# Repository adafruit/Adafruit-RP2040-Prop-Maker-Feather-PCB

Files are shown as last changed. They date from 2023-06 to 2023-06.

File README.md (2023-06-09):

## Adafruit RP2040 Prop-Maker Feather with I2S Audio Amplifier PCB

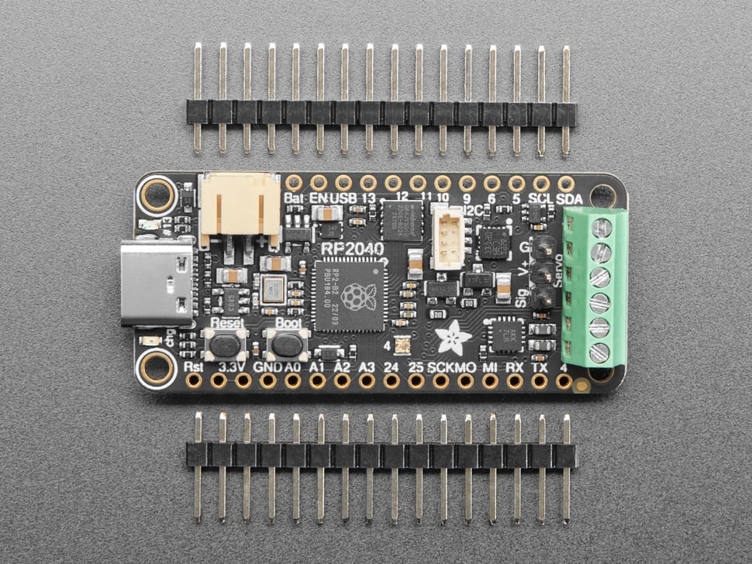
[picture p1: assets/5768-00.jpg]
<a href="http://www.adafruit.com/products/5768"><br/>
Click here to purchase one from the Adafruit shop</a>

PCB files for the Adafruit RP2040 Prop-Maker Feather with I2S Audio Amplifier. 

Format is EagleCAD schematic and board layout
* https://www.adafruit.com/product/5768

### Description

The Adafruit Feather series gives you lots of options for a small, portable, rechargeable microcontroller board. By picking a feather and stacking on a FeatherWing you can create advanced projects quickly. One popular combo is our Feather M4 or Feather RP2040 with a Prop-Maker FeatherWing on top to create animatronics or props that boot up instantly and can drive LEDs, and small speakers.

We've used the Prop-Maker FeatherWing to make lots of lil robots, swords, and other prop projects. However, what if we made it even easier for people to make props? What if we made it so many projects can be built with minimal or no soldering at all? Yeah that would be pretty nice!

Thus, the creation of the Feather P2040 Prop-Maker: an all-in-one combination of the Feather RP2040 with a Prop-Maker FeatherWing with a few tweaks based on feedback from expert prop-builders. Perfect for fitting into your next prop build! This Feather will unlock the prop-maker inside all of us, with tons of stuff packed in to make sabers & swords, props, toys, cosplay pieces, and more.

We looked at hundreds of prop builds, and thought about what would make for a great low-cost (but well-designed) add-on for our Feather boards. Here's what we came up with:

* Terminal Block NeoPixel Port - With easy-to-use screw terminals you can quickly connect and disconnect your NeoPixel strips and rings. This port provides high current drive from either the Feather Lipoly or USB port, whichever is higher. A 5V level up-shifter gives you a clean voltage signal to reduce glitchiness no matter what chip you're using. You can also cut power to the entire strip instantly to reduce quiescent power, thanks to a separate control transistor.
* MAX98357 I2S 3 Watt Class D Audio Amplifier - Drive any 4-8Ω speaker, up to 3 Watts, for sound effects. Audio comes out on two of the terminal blocks so you can screw in any wires to a speaker you like - we're partial to this small 3W speaker with pre-attached wires. Thanks to the I2S digital inputs, you'll get excellent audio quality
* Triple-Axis Accelerometer with Tap Detection - The LIS3DH is our favorite accelerometer, you can use this for detection motion, tilt, or taps. Here's an example of a lightsaber that makes sounds when swung or hit. We have code for this chip in both Arduino and CircuitPython.
* Extra Button or Output Pin - One more pin on the terminal screw block can be used for button input or digital output, for activation or a simple LED.
* Servo Connection - Plug any hobby servo with 3 wires into the 0.1" spaced header, and you can have quick motion control.
* Low power mode! The power system for the NeoPixels and speaker amplifier can be controlled by a pin to cut power to them, so you have lower power usage when the prop is in sleep or off mode (but can wake up fast by listening to the button press or accelerometer data).

At the Feather's heart is an RP2040 chip, clocked at 133 MHz and at 3.3V logic, the same one used in the Raspberry Pi Pico. This chip has a whopping 8 MB of onboard QSPI FLASH and 264K of RAM!  There's even room left over for a STEMMA QT connector for plug-and-play of I2C devices.

To make it easy to use for portable projects, we added a connector for any of our 3.7V Lithium polymer batteries and built in battery charging. You don't need a battery, it will run just fine straight from the USB Type C connector. But, if you do have a battery, you can take it on the go, then plug in the USB to recharge. The Feather will automatically switch over to USB power when it's available.

Here're some handy specs! You get:

* Measures 52.1mm x 22.8mm x 12.2mm / 2.1" x 0.9" x 0.5 without headers soldered in
* Light as a (large?) feather - ~7grams
* RP2040 32-bit Cortex M0+ dual core running at ~133 MHz @ 3.3V logic and power
* 264 KB RAM
* 8 MB SPI FLASH chip for storing files, images, and CircuitPython/MicroPython code storage. No EEPROM
* Tons of GPIO! 21 x GPIO pins with following capabilities:
	* Four 12-bit ADCs (one more than Pico)
	* Two I2C, Two SPI, and two UART peripherals, we label one for the 'main' interface in standard Feather locations
	* 16 x PWM outputs - for servos, LEDs, etc
* Built-in 200mA+ lipoly charger with charging status indicator LED
* Pin #13 red LED for general purpose blinking
* RGB NeoPixel for full-color indication.
* On-board STEMMA QT connector that lets you quickly connect any Qwiic, STEMMA QT or Grove I2C devices with no soldering!
* Both Reset button and Bootloader select button for quick restarts (no unplugging-replugging to relaunch code)
* USB Type C connector lets you access built-in ROM USB bootloader and serial port debugging
* 3.3V regulator with 500mA peak current output and power enable pin
* 4 mounting holes
* 12 MHz crystal for perfect timing.
* Prop-Making section with I2S 3W audio amplifier, 5V NeoPixel level shifting, accelerometer, servo port, and terminal blocks for fast solder-free connections.

Comes assembled and tested, with some header. You'll need a soldering iron to attach the header if you'd like to use it on a breadboard!

### License

Adafruit invests time and resources providing this open source design, please support Adafruit and open-source hardware by purchasing products from [Adafruit](https://www.adafruit.com)!

Designed by Limor Fried/Ladyada for Adafruit Industries.

Creative Commons Attribution/Share-Alike, all text above must be included in any redistribution. 
See license.txt for additional details.

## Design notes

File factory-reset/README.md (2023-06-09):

## Factory Reset file - RP2040 Prop-Maker Feather with I2S Audio Amplifier

This is the factory reset file for the RP2040 Prop-Maker Feather with I2S Audio Amplifier.

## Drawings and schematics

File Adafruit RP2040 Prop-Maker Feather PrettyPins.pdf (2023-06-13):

# Adafruit RP2040 Prop-Maker Feather

# https://www.adafruit.com/product/5768

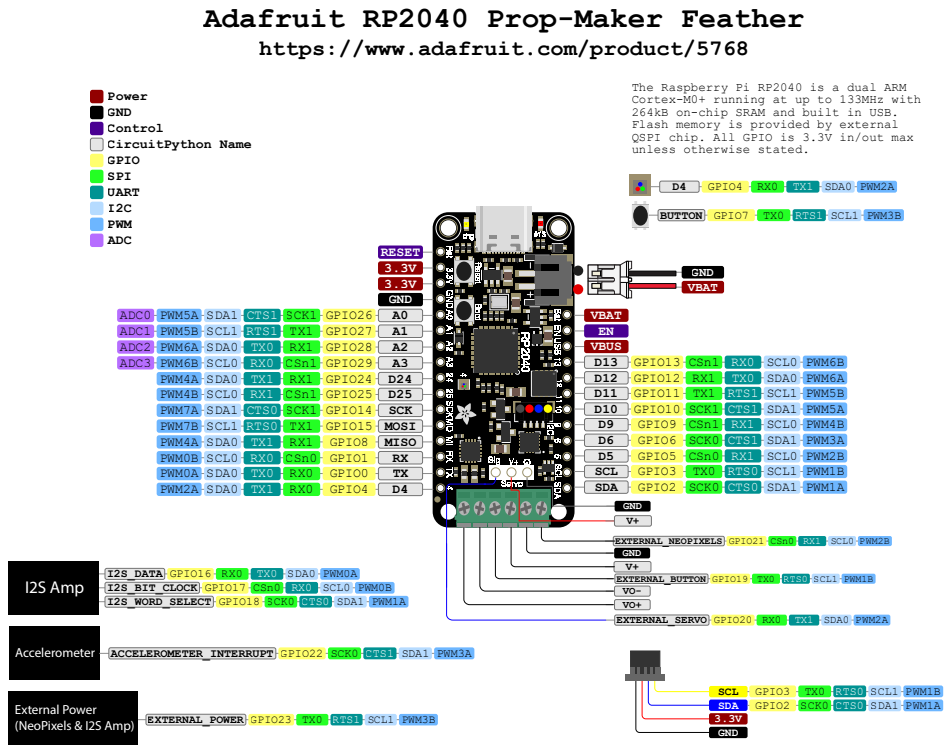
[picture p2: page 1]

The Raspberry Pi RP2040 is a dual ARM
Cortex-M0+ running at up to 133MHz with
264kB on-chip SRAM and built in USB.
Flash memory is provided by external
QSPI chip. All GPIO is 3.3V in/out max
unless otherwise stated.
D4 GPIO4 RX0 TX1 SDA0 PWM2A
BUTTON GPIO7 TX0 RTS1 SCL1 PWM3B

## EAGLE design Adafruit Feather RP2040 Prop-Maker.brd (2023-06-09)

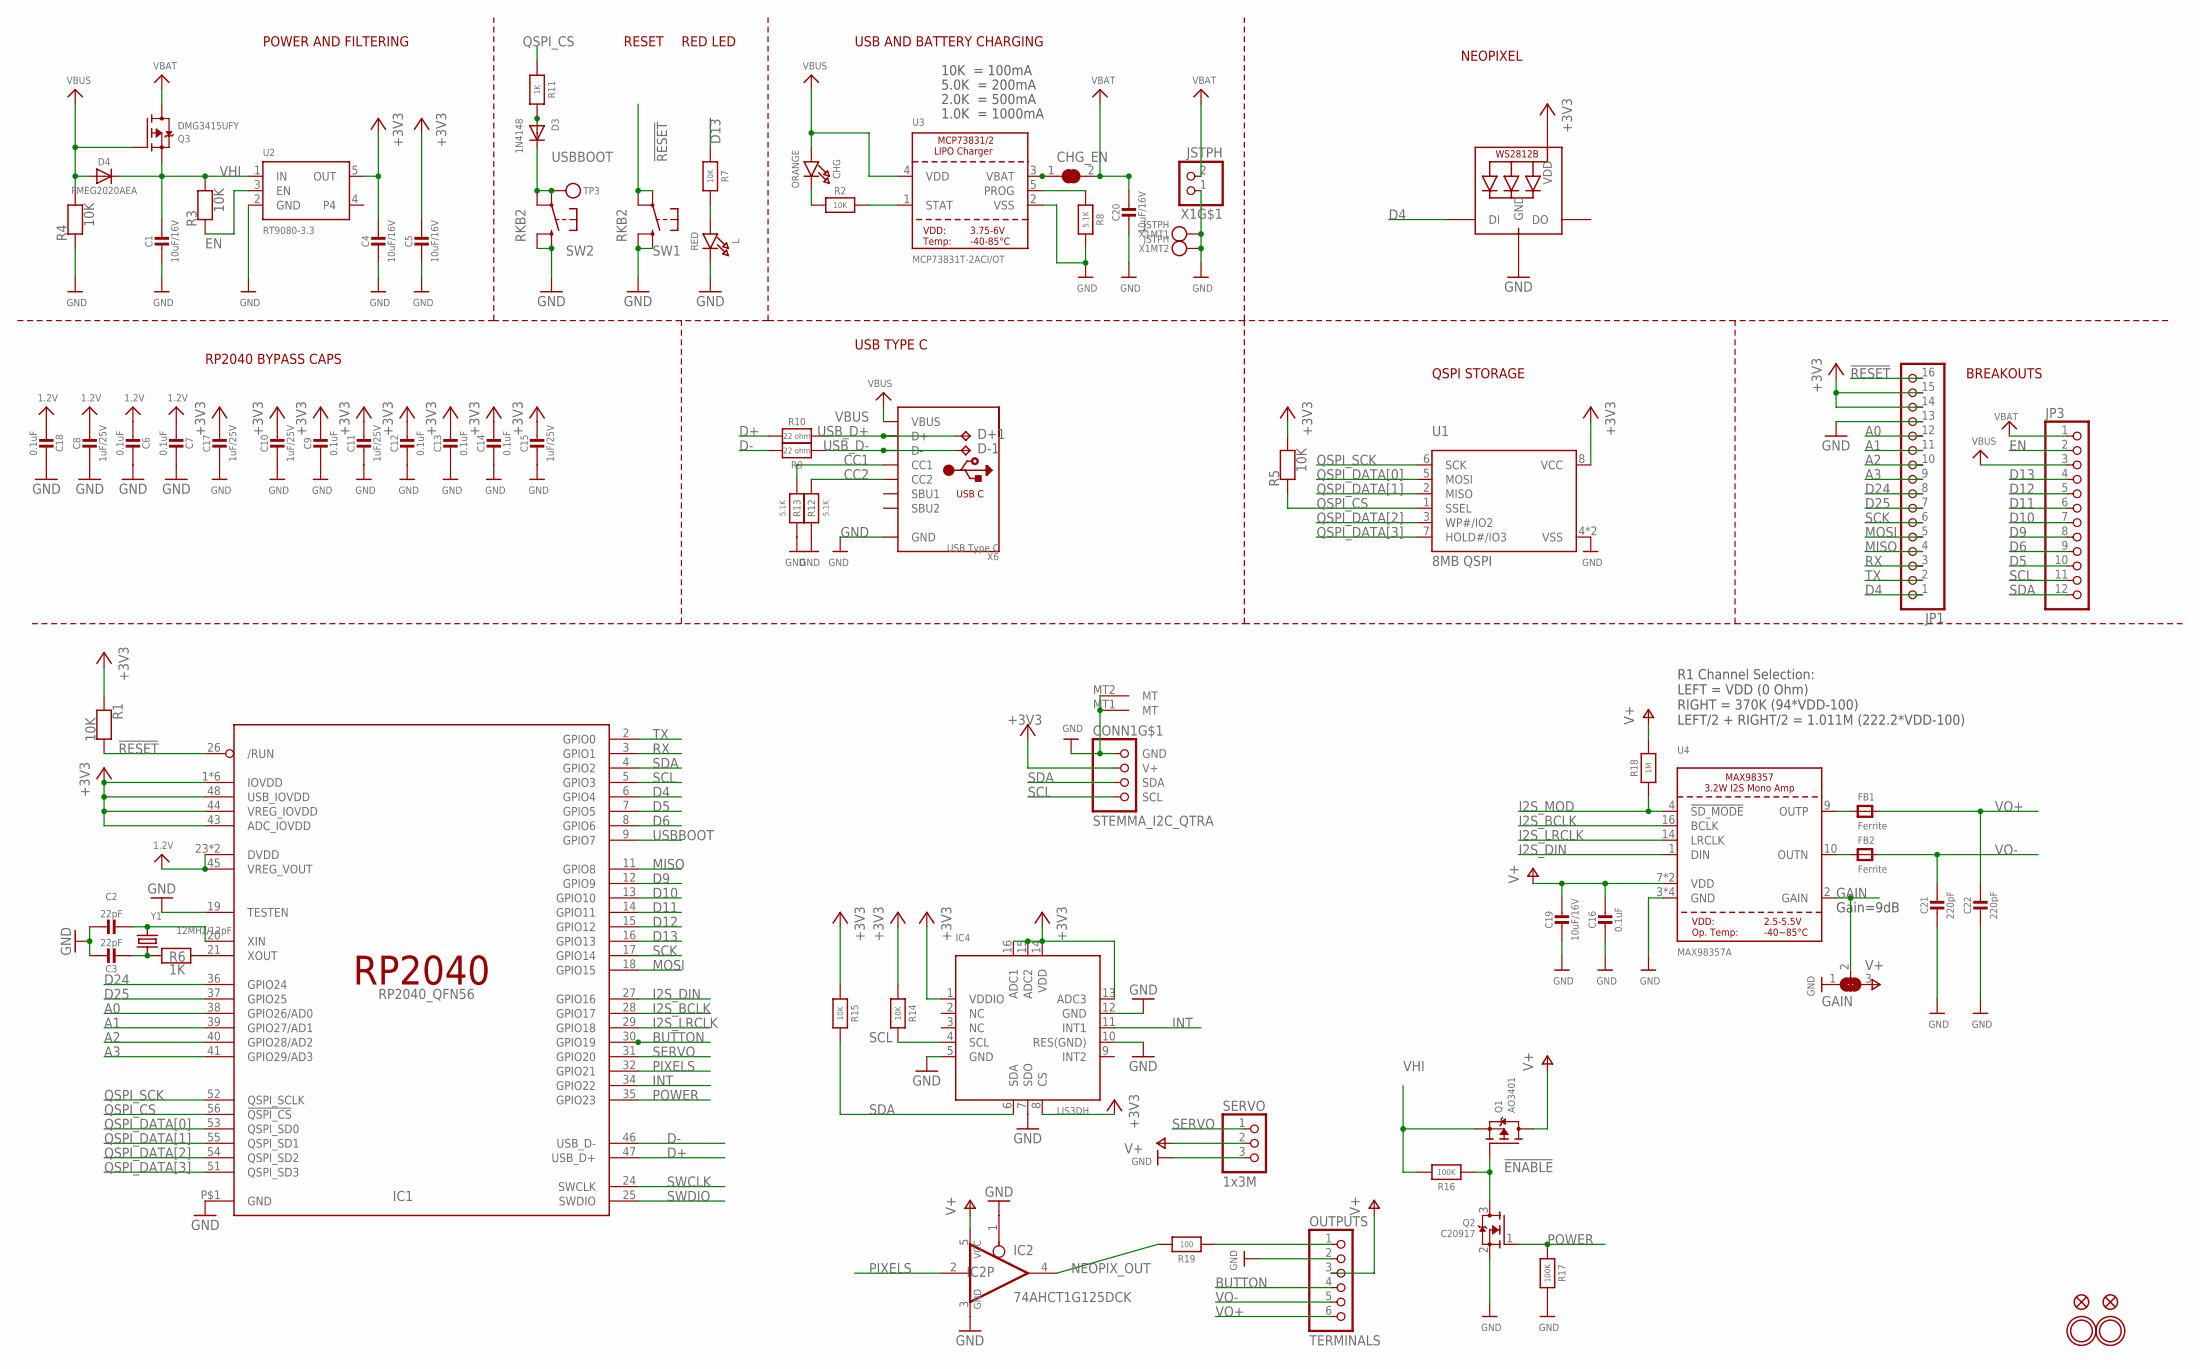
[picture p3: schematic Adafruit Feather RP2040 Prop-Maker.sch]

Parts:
C1, C4, C5, C19, C20: 10uF/16V; 0805-NO
C2, C3: 22pF; _0402NO
C6, C7, C9, C12, C13, C14, C16, C18: 0.1uF; _0402NO
C8, C10, C11, C15, C17: 1uF/25V; _0402NO
C21, C22: 220pF; _0402NO
CHG: ORANGE; CHIPLED_0603_NOOUTLINE
CHG_EN: SOLDERJUMPER_CLOSED; SOLDERJUMPER_CLOSEDWIRE
CONN1: STEMMA_I2C_QTRA; JST_SH4_RA
D3: 1N4148; SOD-323_MINI
D4: PMEG2020AEA; SOD-323F
D+1: TPB1,27; B1,27
D-1: TPB1,27; B1,27
FB1, FB2: Ferrite; 0603-NO
GAIN: SOLDERJUMPER_2WAY; SOLDERJUMPER_2WAY_OPEN_NOPASTE
IC1: RP2040_QFN56; QFN56_7MM_REDUCEDEPAD
IC2: 74AHCT1G125DCK; SC70-5
IC4: LIS3DH; LGA16_3X3MM
JP1: HEADER-1X16ROUND; 1X16_ROUND
JP3: HEADER-1X12; 1X12_ROUND
L: RED; CHIPLED_0603_NOOUTLINE
LED1: WS2812B_SK6805_1515; SK6805_1515
OUTPUTS: TERMINALS; 1X06_OVAL
Q1: AO3401; SOT23-WIDE
Q2: C20917; SOT23-WIDE
Q3: DMG3415UFY; DFN2015-3
R1, R2, R3, R4, R5, R7, R14, R15: 10K; _0402NO
R6, R11: 1K; _0402NO
R8, R12, R13: 5.1K; _0402NO
R9, R10: 22 ohm; _0402NO
R16, R17: 100K; _0402NO
R18: 1M; _0402NO
R19: 100; _0402NO
SERVO: 1x3M; 1X03_ROUND_76
SW1, SW2: RKB2; BTN_RKB2_4.6X2.8
TP3: TESTPOINTROUND1.5MMNO; TESTPOINT_ROUND_1.5MM_NO
U1: 8MB QSPI; USON8_4X4
U2: RT9080-3.3; SOT23-5; JLC_ROTATION 0
U3: MCP73831T-2ACI/OT; SOT23-5; JLC_ROTATION 0
U4: MAX98357A; QFN16_3MM
U$31, U$32: MOUNTINGHOLE2.5; MOUNTINGHOLE_2.5_PLATED
U$34, U$35: FIDUCIAL_1MM
X1: JSTPH; JSTPH2_BATT
X6: USB Type C; USB_C_CUSB31-CFM2AX-01-X
Y1: 12MHz/12pF; CRYSTAL_2.5X2

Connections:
1.2V: C6.2, C7.2, C8.1, C18.2, IC1.23 (DVDD), IC1.45 (VREG_VOUT), IC1.50 (DVDD)
!ENABLE: Q1.1 (G), Q2.3 (D), R16.1
!RESET: IC1.26 (/RUN), JP1.16, R1.2, SW1.A, SW1.A' (P1)
+3V3: C4.1, C5.1, C9.1, C10.1, C11.1, C12.1, C13.1, C14.1, C15.1, C17.1, CONN1.2 (V+), IC1.1 (IOVDD), IC1.10 (IOVDD), IC1.22 (IOVDD), IC1.33 (IOVDD), IC1.42 (IOVDD), IC1.43 (ADC_IOVDD), IC1.44 (VREG_IOVDD), IC1.48 (USB_IOVDD), IC1.49 (IOVDD), IC4.1 (VDDIO), IC4.8 (CS), IC4.13 (ADC3), IC4.14 (VDD), IC4.15 (ADC2), IC4.16 (ADC1), JP1.14, JP1.15, LED1.2 (VDD), R1.1, R5.2, R14.1, R15.1, U1.8 (VCC), U2.5 (OUT)
A0: IC1.38 (GPIO26/AD0), JP1.12
A1: IC1.39 (GPIO27/AD1), JP1.11
A2: IC1.40 (GPIO28/AD2), JP1.10
A3: IC1.41 (GPIO29/AD3), JP1.9
BUTTON: IC1.30 (GPIO19), OUTPUTS.4
CC1: R13.2, X6.A5 (CC1)
CC2: R12.2, X6.B5 (CC2)
D4: IC1.6 (GPIO4), JP1.1, LED1.1 (DI)
D5: IC1.7 (GPIO5), JP3.10
D6: IC1.8 (GPIO6), JP3.9
D9: IC1.12 (GPIO9), JP3.8
D10: IC1.13 (GPIO10), JP3.7
D11: IC1.14 (GPIO11), JP3.6
D12: IC1.15 (GPIO12), JP3.5
D13: IC1.16 (GPIO13), JP3.4, R7.1
D24: IC1.36 (GPIO24), JP1.8
D25: IC1.37 (GPIO25), JP1.7
D+: IC1.47 (USB_D+), R10.2
D-: IC1.46 (USB_D-), R9.2
EN: JP3.2, R3.1, U2.3 (EN)
GAIN: GAIN.2, U4.2 (GAIN)
GND: C1.2, C2.1, C3.1, C4.2, C5.2, C6.1, C7.1, C8.2, C9.2, C10.2, C11.2, C12.2, C13.2, C14.2, C15.2, C16.2, C17.2, C18.1, C19.2, C20.2, C21.2, C22.2, CONN1.1 (GND), CONN1.MT1 (MT), CONN1.MT2 (MT), GAIN.1, IC1.19 (TESTEN), IC1.P$1 (GND), IC2.1 (OE), IC2.3 (GND), IC4.5 (GND), IC4.7 (SDO), IC4.10 (RES(GND)), IC4.12 (GND), JP1.13, L.C, LED1.4 (GND), OUTPUTS.2, Q2.2 (S), R4.1, R8.2, R12.1, R13.1, R17.2, SERVO.3, SW1.B (S), SW1.B' (S1), SW2.B (S), SW2.B' (S1), U1.4 (VSS), U1.PAD (VSS), U2.2 (GND), U3.2 (VSS), U4.3 (GND), U4.11 (GND), U4.15 (GND), U4.THERMAL (GND), X1.1, X1.NC1, X1.NC2, X6.A1B12 (GND), X6.B1A12 (GND)
I2S_BCLK: IC1.28 (GPIO17), U4.16 (BCLK)
I2S_DIN: IC1.27 (GPIO16), U4.1 (DIN)
I2S_LRCLK: IC1.29 (GPIO18), U4.14 (LRCLK)
I2S_MOD: R18.1, U4.4 (!SD_MODE)
INT: IC1.34 (GPIO22), IC4.11 (INT1)
MISO: IC1.11 (GPIO8), JP1.4
MOSI: IC1.18 (GPIO15), JP1.5
unnamed: CHG.C, R2.1
unnamed: L.A, R7.2
unnamed: R2.2, U3.1 (STAT)
unnamed: R8.1, U3.5 (PROG)
unnamed: C2.2, IC1.20 (XIN), Y1.3 (2)
unnamed: C3.2, R6.1, Y1.1
unnamed: IC1.21 (XOUT), R6.2
unnamed: FB2.1, U4.10 (OUTN)
unnamed: FB1.1, U4.9 (OUTP)
unnamed: CHG_EN.1, U3.3 (VBAT)
unnamed: D3.A, R11.2
NEOPIX_OUT: IC2.4 (O), R19.2
PIXELOUT: OUTPUTS.1, R19.1
PIXELS: IC1.32 (GPIO21), IC2.2 (I)
POWER: IC1.35 (GPIO23), Q2.1 (G), R17.1
QSPI_CS: IC1.56 (!QSPI_CS), R5.1, R11.1, U1.1 (SSEL)
QSPI_DATA[0]: IC1.53 (QSPI_SD0), U1.5 (MOSI)
QSPI_DATA[1]: IC1.55 (QSPI_SD1), U1.2 (MISO)
QSPI_DATA[2]: IC1.54 (QSPI_SD2), U1.3 (WP#/IO2)
QSPI_DATA[3]: IC1.51 (QSPI_SD3), U1.7 (HOLD#/IO3)
QSPI_SCK: IC1.52 (QSPI_SCLK), U1.6 (SCK)
RX: IC1.3 (GPIO1), JP1.3
SCK: IC1.17 (GPIO14), JP1.6
SCL: CONN1.4 (SCL), IC1.5 (GPIO3), IC4.4 (SCL), JP3.11, R14.2
SDA: CONN1.3 (SDA), IC1.4 (GPIO2), IC4.6 (SDA), JP3.12, R15.2
SERVO: IC1.31 (GPIO20), SERVO.1
SWCLK: IC1.24 (SWCLK)
SWDIO: IC1.25 (SWDIO)
TX: IC1.2 (GPIO0), JP1.2
USBBOOT: D3.C, IC1.9 (GPIO7), SW2.A, SW2.A' (P1), TP3.P$1
USB_D+: D+1.TP, R10.1, X6.A6 (D+), X6.B6 (D+)
USB_D-: D-1.TP, R9.1, X6.A7 (D-), X6.B7 (D-)
V+: C16.1, C19.1, GAIN.3, IC2.5 (VCC), OUTPUTS.3, Q1.3 (D), R18.2, SERVO.2, U4.7 (VDD), U4.8 (VDD)
VBAT: C20.1, CHG_EN.2, JP3.1, Q3.3 (D), X1.2
VBUS: CHG.A, D4.A, JP3.3, Q3.1 (G), R4.2, U3.4 (VDD), X6.A4B9 (VBUS), X6.B4A9 (VBUS)
VHI: C1.1, D4.C, Q1.2 (S), Q3.2 (S), R3.2, R16.2, U2.1 (IN)
VO+: C22.1, FB1.2, OUTPUTS.6
VO-: C21.1, FB2.2, OUTPUTS.5

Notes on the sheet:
POWER AND FILTERING
RESET
10K = 100mA
5.0K = 200mA
2.0K = 500mA
1.0K = 1000mA
USB AND BATTERY CHARGING
BREAKOUTS
RED LED
RP2040 BYPASS CAPS
USB TYPE C
QSPI STORAGE
NEOPIXEL
R1 Channel Selection: LEFT = VDD (0 Ohm) RIGHT = 370K (94*VDD-100) LEFT/2 + RIGHT/2 = 1.011M (222.2*VDD-100)
Gain=9dB

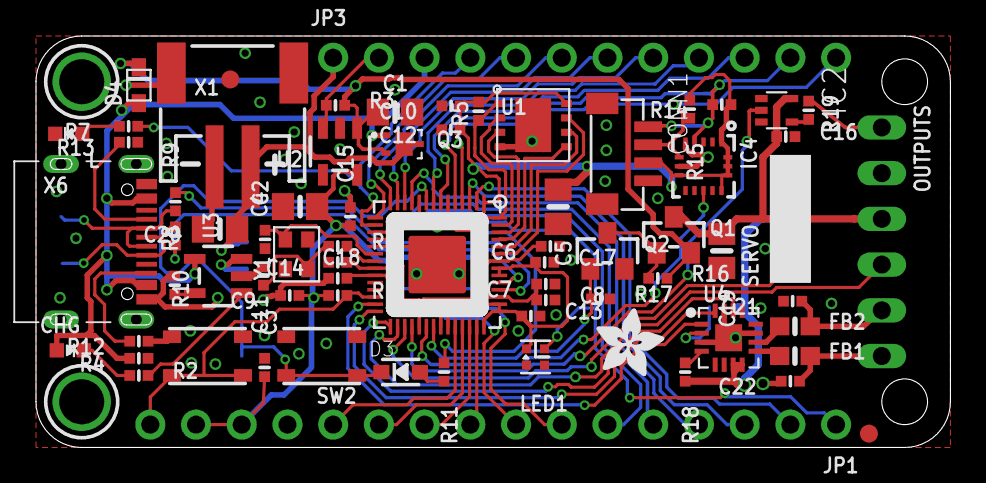
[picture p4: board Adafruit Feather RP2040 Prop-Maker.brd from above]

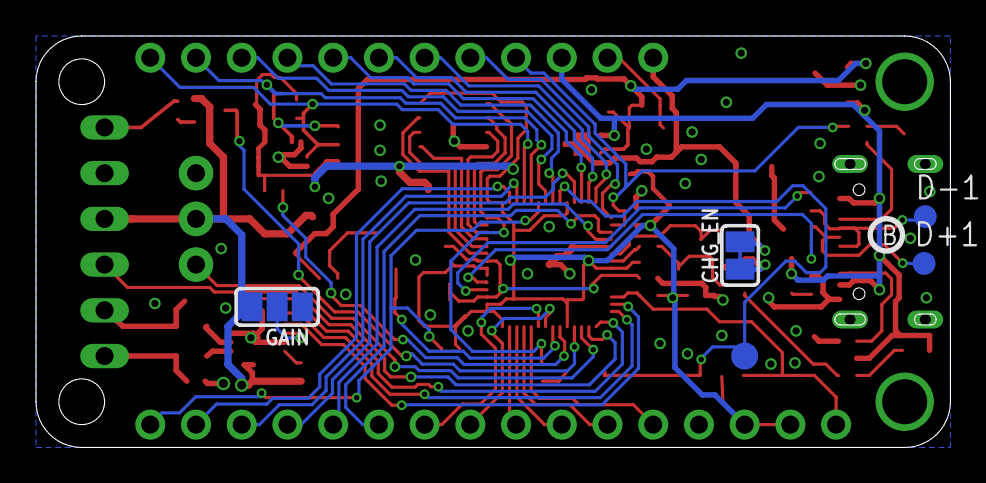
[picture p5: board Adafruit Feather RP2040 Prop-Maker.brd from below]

Board: 2 copper layers, 50.8 x 22.9 mm, 162 parts (51 on the bottom side), 69 nets.

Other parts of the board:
PLABEL0: PLABEL0
PLABEL1: PLABEL1
PLABEL2: PLABEL2
PLABEL3: PLABEL3
PLABEL4: PLABEL4
PLABEL5: PLABEL5
PLABEL6: PLABEL6
PLABEL7: PLABEL7
PLABEL8: PLABEL8
PLABEL9: PLABEL9
PLABEL10: PLABEL10
PLABEL11: PLABEL11
PLABEL12: PLABEL12
PLABEL13: PLABEL13
PLABEL14: PLABEL14
PLABEL15: PLABEL15
PLABEL16: PLABEL16
PLABEL17: PLABEL17
PLABEL18: PLABEL18
PLABEL19, PLABEL26: PLABEL26
PLABEL21: PLABEL21
PLABEL22: PLABEL22
PLABEL23: PLABEL23
PLABEL24: PLABEL24
PLABEL25: PLABEL25
PLABEL27: PLABEL27
PLABEL28: PLABEL28
PLABEL29: PLABEL29
PLABEL30: PLABEL30
PLABEL31: PLABEL31
PLABEL32: PLABEL32
PLABEL33: PLABEL33
PLABEL36: PLABEL36
PLABEL37: PLABEL37
PLABEL38: PLABEL38
PLABEL39: PLABEL39
PLABEL40: PLABEL40
PLABEL41: PLABEL41
PLABEL42: PLABEL42
PLABEL43: PLABEL43
PLABEL44: PLABEL44
PLABEL45: PLABEL45
PLABEL46: PLABEL46
PLABEL47: PLABEL47
PLABEL48: PLABEL48
PLABEL49: PLABEL49
PLABEL50: PLABEL50
PLABEL51: PLABEL51
PLABEL52: PLABEL52
PLABEL53: PLABEL53
PLABEL54: PLABEL54
PLABEL55: PLABEL55
PLABEL56: PLABEL56
PLABEL57: PLABEL57
PLABEL58: PLABEL58
PLABEL59: PLABEL59
PLABEL60: PLABEL60
PLABEL61: PLABEL61
PLABEL62: PLABEL62
PLABEL63: PLABEL63
PLABEL68: PLABEL68
PLABEL69: PLABEL69
PLABEL70: PLABEL70
PLABEL71: PLABEL71
PLABEL72: PLABEL72
PLABEL73: PLABEL73
PLABEL74: PLABEL74
PLABEL75: PLABEL75
PLABEL76: PLABEL76
PLABEL77: PLABEL77
PLABEL78: PLABEL78
PLABEL79: PLABEL79
PLABEL80: PLABEL80
PLABEL81: PLABEL81
PLABEL82: PLABEL82
PLABEL83: PLABEL83
PLABEL84: PLABEL84
PLABEL85: PLABEL85
PLABEL86: PLABEL86
PLABEL87: PLABEL87
PLABEL88: PLABEL88
PLABEL89: PLABEL89
U$13: PCBFEAT-REV-040
U$42: ADAFRUIT_3.5MM

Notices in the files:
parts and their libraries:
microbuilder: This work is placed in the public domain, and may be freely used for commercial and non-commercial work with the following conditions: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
